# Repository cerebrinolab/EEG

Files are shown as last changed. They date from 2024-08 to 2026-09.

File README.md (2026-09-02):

# EEG para analise e neuro-feedback usando Arduino e circuitos DIY.

## Captura

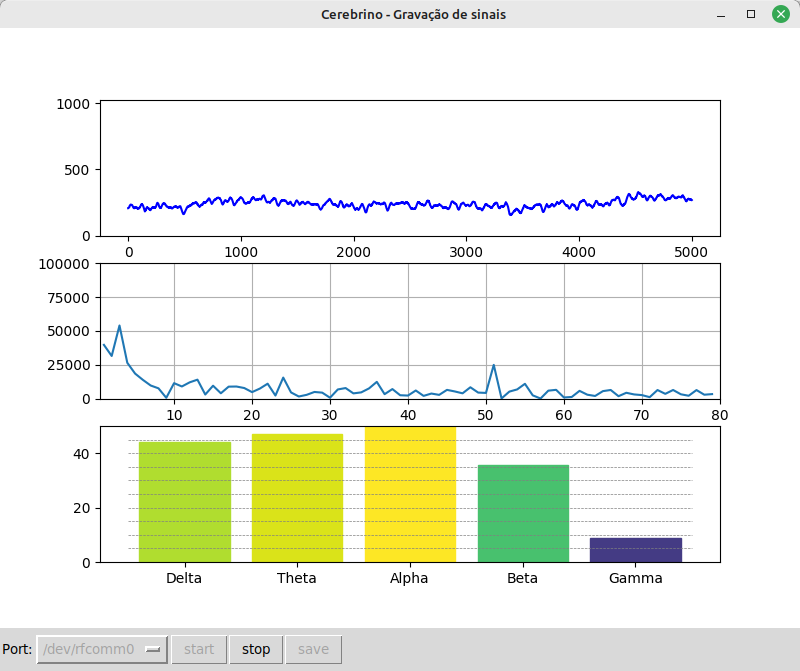
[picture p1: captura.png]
Captura


Essa é a tela de captura, inicialmente com uma interface minimalista, com diferentes gráficos combinados para facilitar a leitura.

Primeiro gráfico - sinal x tempo:
Aqui é possível acompanhar o sinal capturado, o eixo horizontal esta graduado em mili segundos.

Segundo grafico - espectrograma:
Plota o espectro de frequancia, num intervado de 0 á 80Hz

Terceiro grafico - Grafico de barras
Semelhante ao grafico de espectro, permite visualisar de forma simples e direta, as faixas de ondas:
Delta (0 a 4 Hz)
Theta (4 a 8 Hz)
Alpha (8 a 13 Hz)
Beta (13 a 30 Hz)
Gama (30 a 80 Hz)

## Análise por Inteligência Artificial

O sinal do gráfico abaixo foi processado por I.A., treinada com datasets etiquetados para olhos abertos, fechados, piscadas e movimentos musculares.
Esse sinal com duração de 6 minutos, alternando minuto a minuto entre olhos abertos e olhos fechados, iniciando com os olhos abertos.
Atualmente a análise é feita offline, mas o objetivo é que a I.A. efetue a análise em tempo real e que a interface traduza o resultado em estímulos sonoros e visuais, possibilitando que o usuário possa aprender a controlar seus estados mentais.

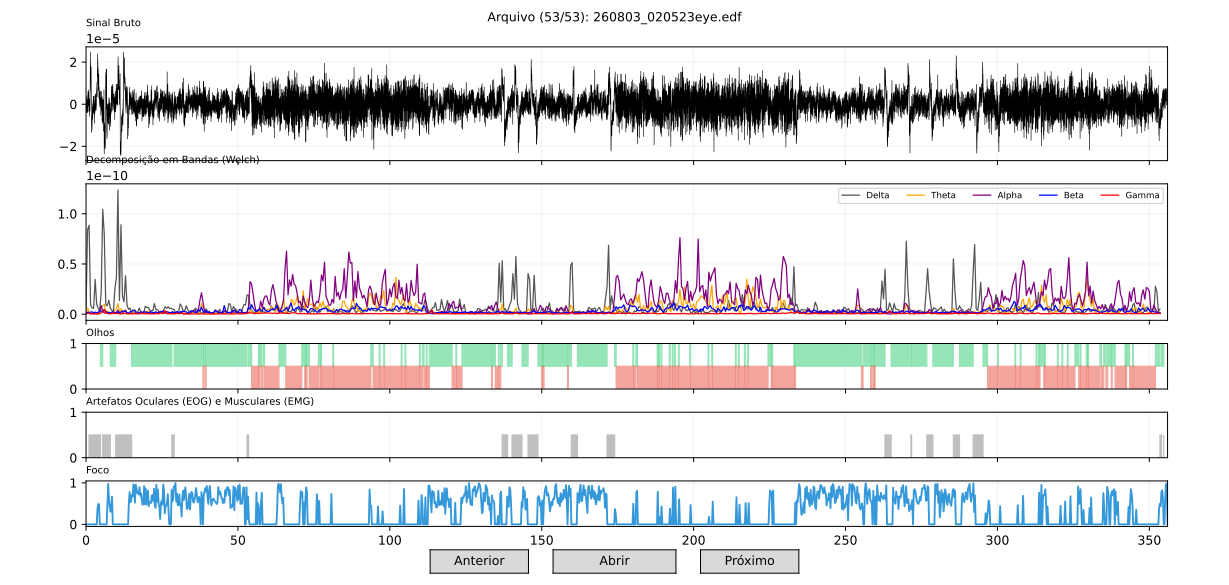
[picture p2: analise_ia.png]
Análise


## Placa
Circuito de aquisição de sinais

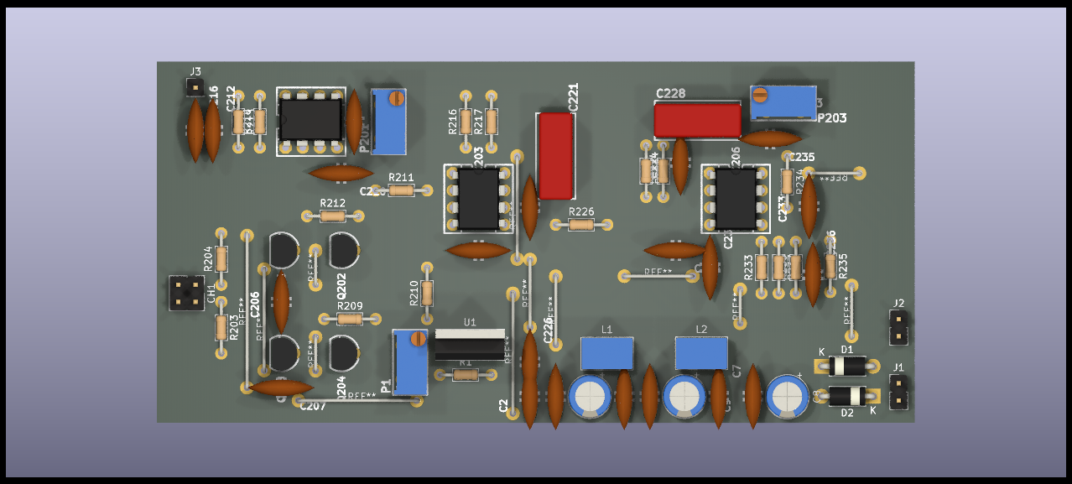
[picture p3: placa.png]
Placa


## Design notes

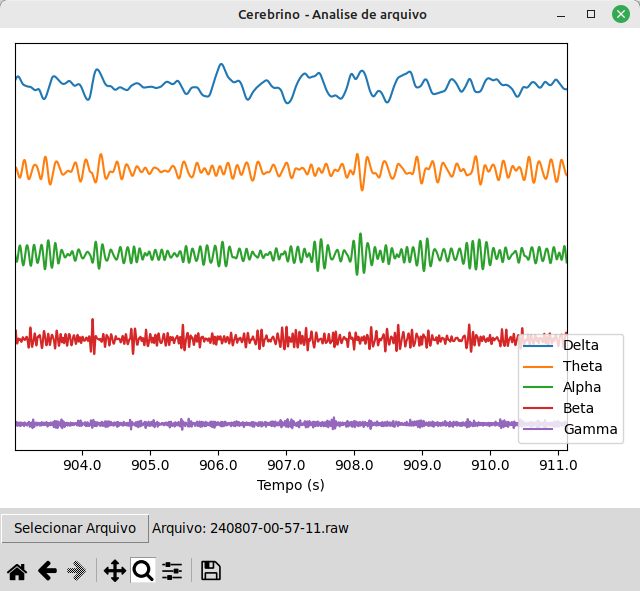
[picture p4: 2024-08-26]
analise.png

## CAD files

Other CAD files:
kicad/3D/modelo-jumper.blend

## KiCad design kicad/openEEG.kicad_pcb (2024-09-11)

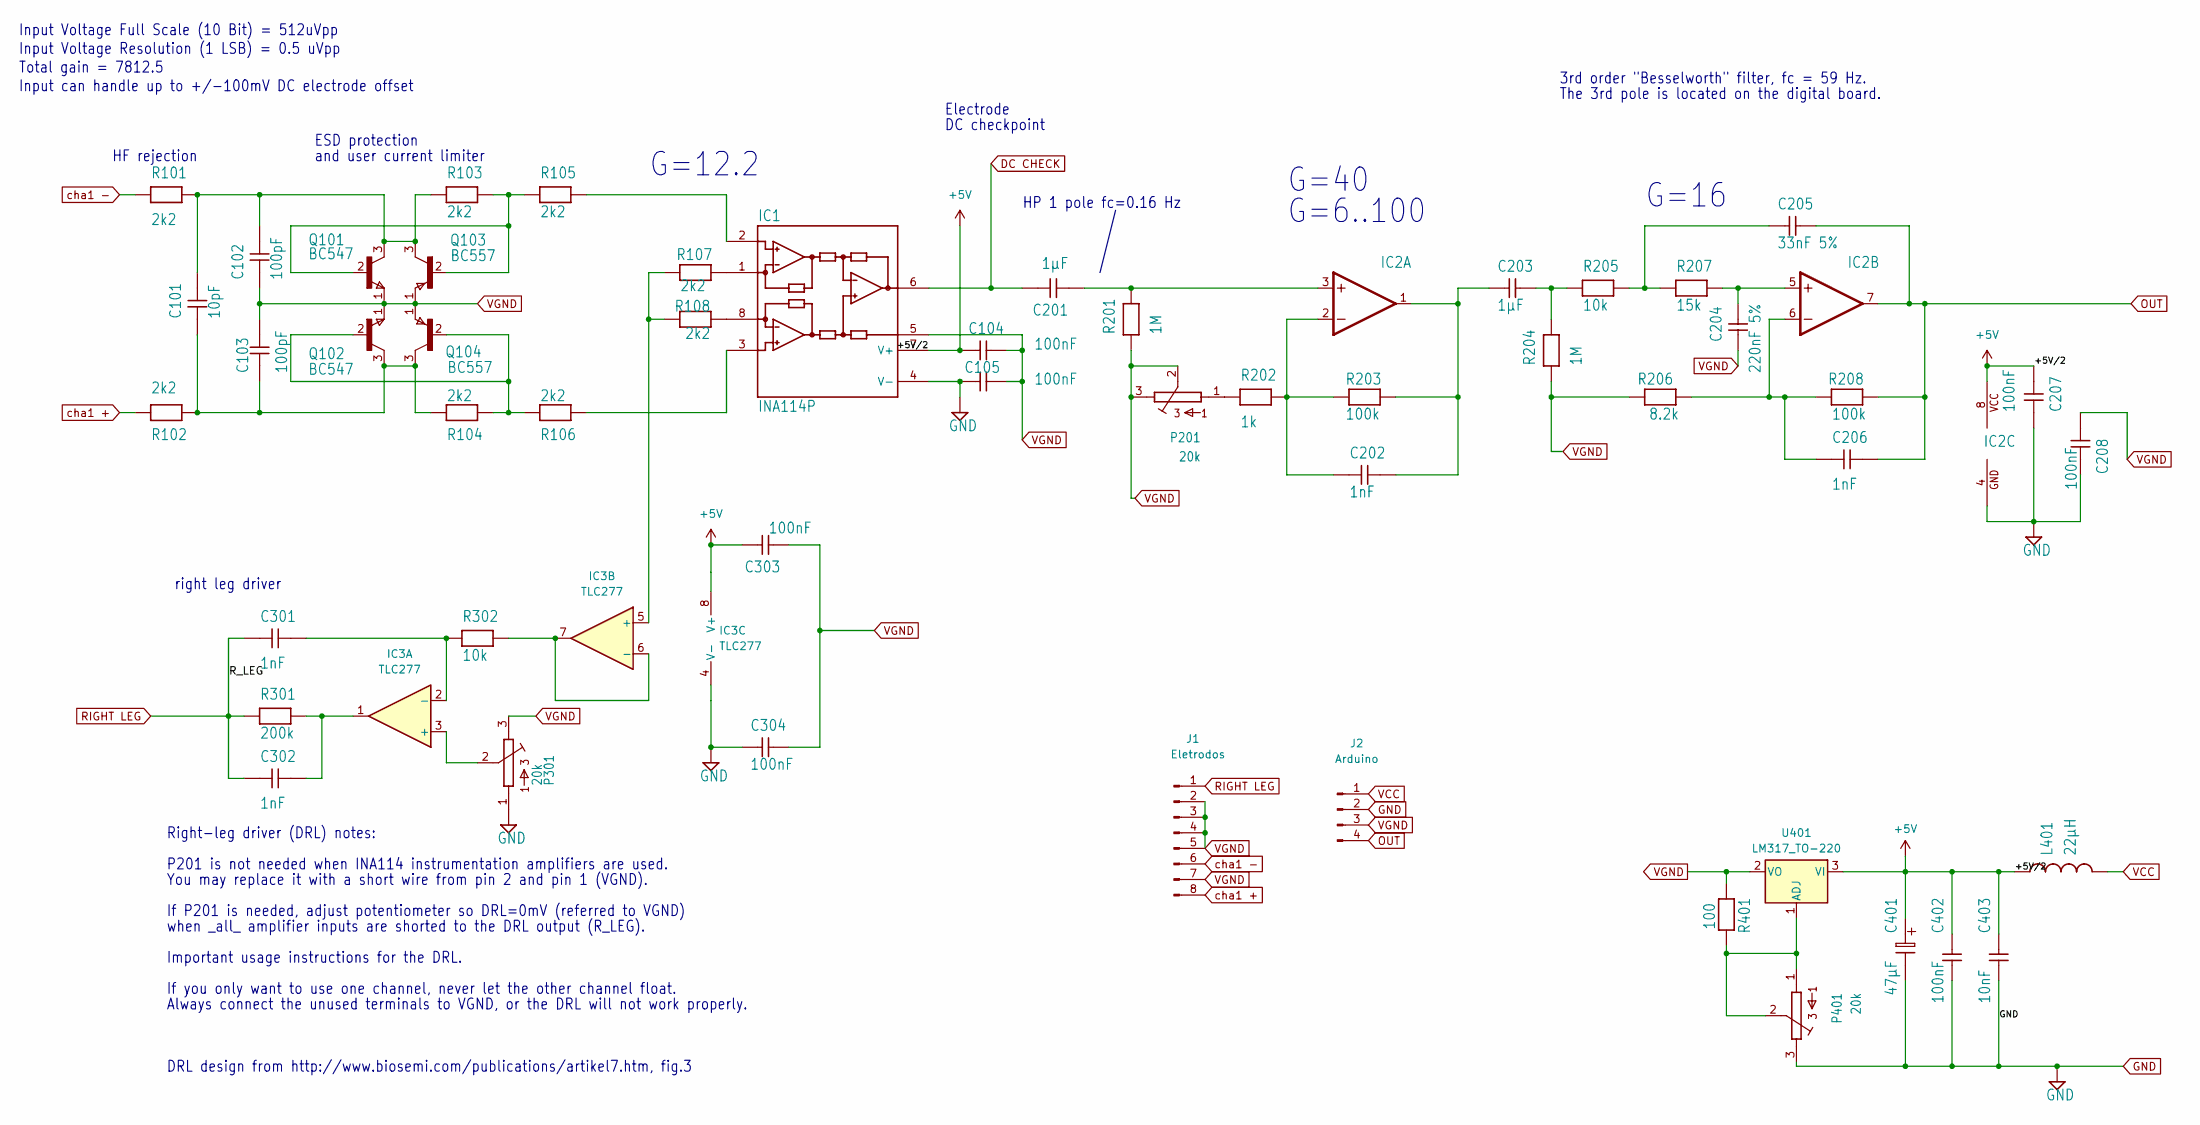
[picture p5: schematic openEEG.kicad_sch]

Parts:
C101: 10pF; R_Axial_DIN0204_L3.6mm_D1.6mm_P2.54mm_Vertical
C102, C103: 100pF; R_Axial_DIN0204_L3.6mm_D1.6mm_P2.54mm_Vertical
C104, C105, C207, C208, C303, C304, C402: 100nF; R_Axial_DIN0204_L3.6mm_D1.6mm_P2.54mm_Vertical
C201, C203: 1µF; CP_Radial_Tantal_D4.5mm_P2.50mm
C202, C206, C301, C302: 1nF; R_Axial_DIN0204_L3.6mm_D1.6mm_P2.54mm_Vertical
C204: 220nF 5%; R_Axial_DIN0204_L3.6mm_D1.6mm_P2.54mm_Vertical
C205: 33nF 5%; R_Axial_DIN0204_L3.6mm_D1.6mm_P2.54mm_Vertical
C401: 47µF; CP_Radial_D5.0mm_P2.50mm
C403: 10nF; R_Axial_DIN0204_L3.6mm_D1.6mm_P2.54mm_Vertical
IC1: INA114P; DIL-08
IC2: TLC277P; DIL-08
IC3: TLC277; DIL-08
J1: Eletrodos; PinHeader_2x04_P2.54mm_Vertical
J2: Arduino; PinHeader_1x04_P2.54mm_Vertical
L401: 22µH; L_Radial_L7.5mm_W4.6mm_P5.00mm_Neosid_SD75
P201, P301, P401: 20k; Potentiometer_Bourns_3386P_Vertical
Q101, Q102: BC547; TO92alinhado
Q103, Q104: BC557; TO92alinhado
R101, R102, R103, R104, R107, R108: 2k2; R_Axial_DIN0204_L3.6mm_D1.6mm_P2.54mm_Vertical
R105, R106: 2k2; R_Axial_DIN0204_L3.6mm_D1.6mm_P5.08mm_Vertical
R201, R204: 1M; R_Axial_DIN0204_L3.6mm_D1.6mm_P2.54mm_Vertical
R202: 1k; R_Axial_DIN0204_L3.6mm_D1.6mm_P2.54mm_Vertical
R203, R208: 100k; R_Axial_DIN0204_L3.6mm_D1.6mm_P2.54mm_Vertical
R205: 10k; R_Axial_DIN0204_L3.6mm_D1.6mm_P2.54mm_Vertical
R206: 8.2k; R_Axial_DIN0204_L3.6mm_D1.6mm_P2.54mm_Vertical
R207: 15k; R_Axial_DIN0204_L3.6mm_D1.6mm_P2.54mm_Vertical
R301: 200k; R_Axial_DIN0204_L3.6mm_D1.6mm_P2.54mm_Vertical
R302: 10k; R_Axial_DIN0204_L3.6mm_D1.6mm_P7.62mm_Horizontal
R401: 100; R_Axial_DIN0204_L3.6mm_D1.6mm_P2.54mm_Vertical
U401: LM317_TO-220; TO-220-3_Vertical

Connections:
+5V: C104.1, C207.2, C303.2, C401.1, C402.2, C403.2, IC1.7 (V+), IC2.8 (VCC), IC3.8 (V+), L401.1, U401.3 (VI)
DC CHECK: C201.2, IC1.6 (OUT)
GND: C105.1, C207.1, C208.1, C304.1, C401.2, C402.1, C403.1, IC1.4 (V-), IC2.4 (GND), IC3.4 (V-), J2.2, P301.1, P401.3
unnamed: C203.2, R204.2, R205.1
unnamed: C205.1, R205.2, R207.1
unnamed: C302.2, IC3.1, R301.2
unnamed: IC1.3 (+IN), R106.2
unnamed: IC1.2 (-IN), R105.2
unnamed: IC1.1 (RG), R107.1
unnamed: IC1.8 (RG@1), R108.1
unnamed: C201.1, IC2.3 (+IN), R201.2
unnamed: C202.1, IC2.2 (-IN), R202.2, R203.1
unnamed: C202.2, C203.1, IC2.1 (OUT), R203.2
unnamed: C204.2, IC2.5 (+IN), R207.2
unnamed: C206.1, IC2.6 (-IN), R206.2, R208.1
unnamed: IC3.3 (+), P301.2
unnamed: C301.2, IC3.2 (-), R302.1
unnamed: IC3.5 (+), R107.2, R108.2
unnamed: IC3.6 (-), IC3.7, R302.2
unnamed: P201.1, R202.1
unnamed: Q101.2 (B), Q103.2 (B), R103.2, R105.1
unnamed: C101.2, C102.2, Q101.3 (C), Q103.3 (C), R101.2, R103.1
unnamed: Q102.2 (B), Q104.2 (B), R104.2, R106.1
unnamed: C101.1, C103.1, Q102.3 (C), Q104.3 (C), R102.2, R104.1
unnamed: P401.1, P401.2, R401.1, U401.1 (ADJ)
OUT: C205.2, C206.2, IC2.7 (OUT), J2.4, R208.2
RIGHT LEG: C301.1, C302.1, J1.1, R301.1
VCC: J2.1, L401.2
VGND: C102.1, C103.2, C104.2, C105.2, C204.1, C208.2, C303.1, C304.2, IC1.5 (REF), J1.2, J1.3, J1.4, J1.5, J1.7, J2.3, P201.2, P201.3, P301.3, Q101.1 (E), Q102.1 (E), Q103.1 (E), Q104.1 (E), R201.1, R204.1, R206.1, R401.2, U401.2 (VO)
cha1 +: J1.8, R102.1
cha1 -: J1.6, R101.1

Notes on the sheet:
Input can handle up to +/-100mV DC electrode offset
Input Voltage Full Scale (10 Bit) = 512uVpp
If P201 is needed, adjust potentiometer so DRL=0mV (referred to VGND)
HP 1 pole fc=0.16 Hz
P201 is not needed when INA114 instrumentation amplifiers are used.
right leg driver
G=12.2
Electrode
G=16
G=6..100
DRL design from http://www.biosemi.com/publications/artikel7.htm, fig.3
when _all_ amplifier inputs are shorted to the DRL output (R_LEG).
and user current limiter
3rd order "Besselworth" filter, fc = 59 Hz.
If you only want to use one channel, never let the other channel float.
DC checkpoint
Input Voltage Resolution (1 LSB) = 0.5 uVpp
Important usage instructions for the DRL.
ESD protection
You may replace it with a short wire from pin 2 and pin 1 (VGND).
The 3rd pole is located on the digital board.
Always connect the unused terminals to VGND, or the DRL will not work properly.
G=40
Right-leg driver (DRL) notes:
HF rejection
Total gain = 7812.5

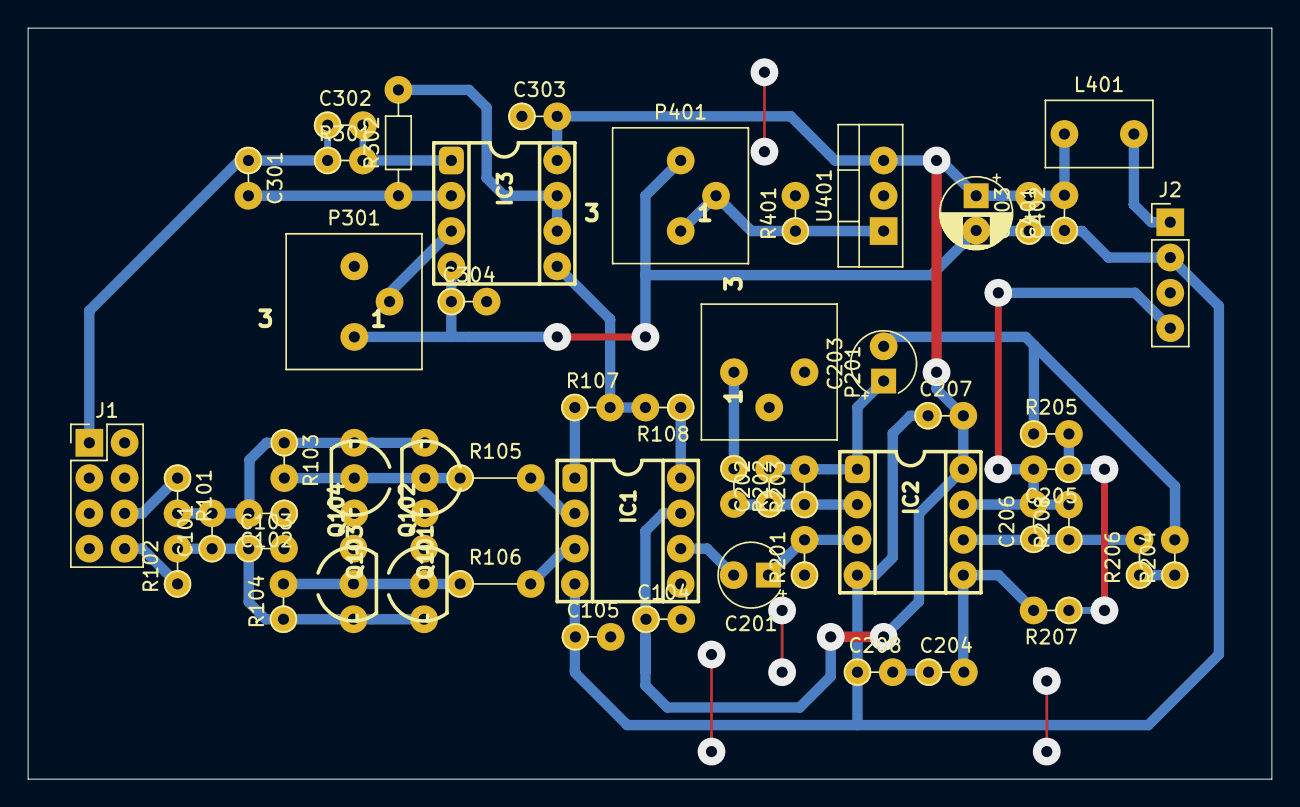
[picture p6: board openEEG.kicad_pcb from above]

Board: 2 copper layers, 89.5 x 54.1 mm, 53 parts (0 on the bottom side), 31 nets.

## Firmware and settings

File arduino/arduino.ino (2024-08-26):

#include "Arduino.h"

// Define o pino de entrada analógica
#define ANALOG_PIN A0

// Define a taxa de transmissão da serial
#define BAUD_RATE 115200

// Cria uma variável para armazenar o valor analógico
int analogValue = 0;

// Função de interrupção do timer
ISR(TIMER2_COMPA_vect) {
    // Lê o valor do pino analógico A0 e armazena na variável analogValue
    analogValue = analogRead(ANALOG_PIN);

    // Converte o valor analógico (10 bits) em dois bytes
    uint8_t byteAlto = (uint8_t(analogValue >> 7) & 0x07) | 0x80;
    uint8_t byteBaixo = analogValue & 0x7F;

    Serial.write(byteAlto);
    Serial.write(byteBaixo);
}



void setup() {
  // Configura o timer
  noInterrupts();
   // Clear registers
  TCCR2A = 0;
  TCCR2B = 0;
  TCNT2 = 0;

  // 1000 Hz (16000000/((124+1)*128))
  OCR2A = 124;
  // CTC
  TCCR2A |= (1 << WGM21);
  // Prescaler 128
  TCCR2B |= (1 << CS22) | (1 << CS20);
  // Output Compare Match A Interrupt Enable
  TIMSK2 |= (1 << OCIE2A);
  interrupts();

  // Inicia a comunicação serial
  Serial.begin(BAUD_RATE);
}

void loop() {
  //  All the work is done in the timer interrupt service routine (ISR) 
  return;
}

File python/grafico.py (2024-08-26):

from matplotlib.figure import Figure
from matplotlib.backends.backend_tkagg import FigureCanvasTkAgg, NavigationToolbar2Tk
import numpy as np
from scipy.signal import butter, lfilter
import tkinter as tk
import matplotlib.cm as cm  # Adiciona a linha de importação

def filtro_passa_faixa(sinal, lowcut, highcut, fs=1000):
    """
    Aplica um filtro passa-faixa Butterworth de segunda ordem.

    Args:
      sinal: Lista de dados do sinal.
      lowcut: Frequência de corte inferior do filtro em Hz.
      highcut: Frequência de corte superior do filtro em Hz.
      fs: Frequência de amostragem do sinal em Hz.

    Returns:
      sinais_filtrados: Lista de dados do sinal filtrado.
    """

    nyq = 0.5 * fs
    low = lowcut / nyq
    high = highcut / nyq
    b, a = butter(3, [low, high], btype='band')
    return lfilter(b, a, sinal)

# aplica filtros e retorna uma lista de sinais
def aplicar_filtros(sinal):
    return [
        filtro_passa_faixa(sinal, 2, 4),
        filtro_passa_faixa(sinal, 4, 8),
        filtro_passa_faixa(sinal, 8, 13),
        filtro_passa_faixa(sinal, 13, 30),
        filtro_passa_faixa(sinal, 30, 80),
        # np.array(sinal),
    ]

class gfCaptura:
    """
    Classe responsável por criar e gerenciar o gráfico de sinal.
    """
    def __init__(self, master, tipo='padrao', sampling_rate=1000):
        """
        Inicializa o gráfico.

        Args:
            master: A janela principal Tkinter.
            tipo: Tipo de gráfico (padrao ou analise).
            sampling_rate: Taxa de amostragem do sinal.
        """
        self.master = master
        self.fig = Figure(figsize=(8, 6), dpi=100)
        self.fig.tight_layout = True
        self.fs = sampling_rate
        self.ax1 = self.fig.add_subplot(3, 1, 1)  # Sinal original
        self.ax2 = self.fig.add_subplot(3, 1, 2)  # Espectrograma
        self.ax3 = self.fig.add_subplot(3, 1, 3)  # Gráfico de colunas
        self.buffer = []
        self.tipo = tipo

        # Define os limites dos eixos y para os subplots
        self.ax1.set_ylim(0, 1023)
        self.ax2.set_ylim(0, 1)  # Limite para o espectro
        self.ax3.set_ylim(0, 100000)  # Limite para o gráfico de colunas

        # Cria a tela Tkinter para o gráfico
        self.canvas = FigureCanvasTkAgg(self.fig, master=self.master)
        self.canvas.draw()  # Renderiza o gráfico inicialmente

        # Adiciona a toolbar se o tipo do gráfico for "analise"
        if tipo == "analise":
            self.toolbar = NavigationToolbar2Tk(self.canvas, self.master)
            self.toolbar.update()
            self.canvas.get_tk_widget().pack(side=tk.TOP, fill=tk.BOTH, expand=True)

    def atualiza(self, sinal):
        """
        Atualiza o gráfico com novos dados.

        Args:
            sinal: Lista de dados do sinal.
        """
        self.buffer = sinal
        self.ax1.cla()  # Limpa o subplot do sinal original
        self.ax2.cla()  # Limpa o subplot do espectrograma
        self.ax3.cla()  # Limpa o subplot do gráfico de colunas
        self.ax1.plot(self.buffer, color='b')  # Plota o sinal original
        self.ax1.set_ylim(0, 1023)
        self.ax2.set_ylim(0, 100000)
        self.plota_espectrograma(self.buffer)
        self.plota_grafico_colunas(self.buffer)  # Plota o gráfico de colunas
        self.canvas.draw()  # Atualiza a tela do gráfico

    def fecha(self):
        """Fecha a janela do gráfico."""
        print("Grafico.fecha()")
        self.master.destroy()

    def on_close(self, event):
        """Fecha a janela do gráfico quando o botão de fechar é clicado."""
        print("Grfico.on_close()")
        self.fecha()

    def ativo(self):
        """Verifica se a janela do gráfico está ativa."""
        print("Grafico.ativo()")
        return self.master.winfo_exists()

    def plota_espectrograma(self, sinal):
        """
        Plota o espectrograma do sinal.

        Args:
            sinal: Lista de dados do sinal.
        """
        # Aguarda o buffer atingir 5000 antes de plotar o espectrograma
        if (len(sinal) >= 5000):
            # Cria um vetor de tempo com base no comprimento da lista de inteiros
            t = np.linspace(0, 1, len(sinal))

            # Calcula a FFT do sinal
            freq = np.fft.fftfreq(len(sinal), d=t[1] - t[0])
            espectro = np.fft.fft(sinal)

            # Filtra as frequências negativas
            espectro = espectro[:len(espectro) // 2]
            freq = freq[:len(freq) // 2]

            # Encontra o índice das frequências desejadas (0.5 Hz a 80 Hz)
            indice_min = np.argmin(np.abs(freq - 0.5))
            indice_max = np.argmin(np.abs(freq - 80))

            # Plota o espectrograma
            self.ax2.plot(freq[indice_min:indice_max], np.abs(espectro[indice_min:indice_max]))
            self.ax2.set_xlim(0.5, 80)
            self.ax2.grid(True)

    def plot_sinal(self, sinal):
        """
        Plota os dados de uma lista de sinais.
        """
        sinais = self.aplicar_filtros(sinal)

        self.ax.clear()
        # Plota os sinais filtrados
        self.ax.set_xlabel("Tempo (s)")

        # Plota cada sinal com um deslocamento vertical
        labels = ["Delta", "Theta", "Alpha", "Beta", "Gamma", "Bruto"]  # Lista de labels
        for i, sinal in enumerate(sinais):
            self.ax.plot(sinal + 800 - i * 200, label=labels[i])  # Plota no mesmo subplot

        # Configura os ticks do eixo x para o último subplot
        self.ax.set_xticks(range(0, len(sinais[0]), 1000))
        self.ax.set_xticklabels([str(i / 1000) for i in range(0, len(sinais[0]), 1000)])
        self.ax.set_yticks([])  # Remove os ticks do eixo y do último subplot

        # Coloca a legenda do lado esquerdo do gráfico
        self.ax.legend(loc='lower left', bbox_to_anchor=(0.9, 0))  # Altera a posição da legenda

        self.canvas.draw()



    import matplotlib.cm as cm
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

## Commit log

2024-08-26 arquivo de exemplo
2024-09-11 publicação do circuito
    [modelo-jumper.blend, openEEG.kicad_pcb, openEEG.kicad_sch]
2026-09-06 Recupera pasta kicad deletada
    [modelo-jumper.blend, openEEG.kicad_pcb, openEEG.kicad_sch]
